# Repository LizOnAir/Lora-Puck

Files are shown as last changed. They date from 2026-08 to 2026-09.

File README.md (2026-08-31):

# Lora-Puck
A Lora module with a AHT20 sensors and LCD display to show status. I made this to discover about how to use LoRa for communication.

Screenshot 2026-08-31 at 10 58 07 PM

## Features:
- detect humidity
- detect temperature
- send data via Lora
- low power consumption
- display

## PCB
PCBMODEL

### Schematic
Screenshot 2026-08-13 at 10 35 21 PM

### Layout
Screenshot 2026-08-13 at 10 35 02 PM
Screenshot 2026-08-13 at 10 35 05 PM

Access files in [PCB folder](https://github.com/LizOnAir/Lora-Puck/tree/main/PCB).

For this design, I'm using PCBA from JLCPCB.

## CAD
Screenshot 2026-08-31 at 10 58 07 PM
Screenshot 2026-08-31 at 10 58 02 PM
Screenshot 2026-08-31 at 10 58 21 PM

Made in Fusion360.Liz
Access files in [CAD folder](https://github.com/LizOnAir/Lora-Puck/tree/main/CAD).

### Assembly
1.  Insert 4 heatset onto the 4 mounting holes in the bottom case.
2.  Insert the PCB into the bottom case.
3.  Using hot glue, stick the buttons onto the tactile switches.
4.  Align the holes of PCB onto the holes of the bottom case.
5.  Cover the top case over the bottom case.
6.  Screw them tight together.
7.  Charge the battery and hang it on somewhere to start detect temperature!!

## Firmware
I use Arduino IDE for programming.
- display
- sensors
- sending data via lora

Access files in [Firmware folder](https://github.com/LizOnAir/Lora-Puck/tree/main/Firmware).

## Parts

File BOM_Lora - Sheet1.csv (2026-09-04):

Item Description | Quantity | Price | Source
PCBA: | 1 |  | https://cart.jlcpcb.com/quote?spm=Jlcpcb.Homepage.1006&spm=Jlcpcb.Homepage.1006
Setup Fee |  | $25.56
Stencil |  | $8.21
Panel |  | $0.00
Large Size |  | $0.00
Components (15 items) |  | $61.35
Feeders Loading Fee |  | $21.42
SMT Assembly |  | $1.40
Hand-soldering Labor Fee |  | $3.58
Manual Assembly |  | $0.08
X-Ray Inspection |  | $16.40
Packaging Fee |  | $0.49
Total Standard PCBA Price |  | $138.49

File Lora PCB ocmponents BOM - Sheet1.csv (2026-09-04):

Designator | Comment | Footprint | Manufacturer | Footprint | JLCPCB Part # | Product link | Lib Type | Rec. Order Qty | Unit Price ($) | Total Price ($)
C11,C2,C3 | 10UF | 402 | Samsung Electro-Mechanics | 402 | C15525 | https://jlcpcb.com/partdetail/16204-CL05A106MQ5NUNC/C15525 | Basic | 20 | 0.0256 | 0.512
J1 | USB_C_Receptacle_USB2.0_14P | USB_C_Receptacle_G-Switch_GT-USB-7010ASV | SHOU HAN | USB_C_Receptacle_G-Switch_GT-USB-7010ASV | C2765186 | https://jlcpcb.com/partdetail/SHOUHAN-TYPE_C_16PIN_2MD_073/C2765186 | Extended | 3 | 0.0743 | 0.2229
SW1,SW2 | SW_Push | SW_SPST_TS-1088-xR020 | XUNPU | SW_SPST_TS-1088-xR020 | C720477 | https://jlcpcb.com/partdetail/XUNPU-TS_1088AR02016/C720477 | Basic | 8 | 0.0556 | 0.4448
L1 | 15uH | 603 | microgate | 603 | C486329 | https://jlcpcb.com/partdetail/microgate-MGFL1608F150MTLF/C486329 | Extended | 6 | 0.0384 | 0.2304
R1,R2 | 5.1k | 402 | UNI-ROYAL(Uniroyal Elec) | 402 | C25905 | https://jlcpcb.com/partdetail/26648-0402WGF5101TCE/C25905 | Basic | 20 | 0.0026 | 0.052
Y1 | 32MHz | Crystal_SMD_Abracon_ABM10-4Pin_2.5x2.0mm | NDK | Crystal_SMD_Abracon_ABM10-4Pin_2.5x2.0mm | C843260 | https://jlcpcb.com/partdetail/NDK-NX2016SA_32MHZ_STD_CZS5/C843260 | Extended | 5 | 0.3518 | 1.759
R5,R6 | 10k | 402 | UNI-ROYAL(Uniroyal Elec) | 402 | C25744 | https://jlcpcb.com/partdetail/26487-0402WGF1002TCE/C25744 | Basic | 20 | 0.0031 | 0.062
U2 | SX1262IMLTRT | QFN-24-1EP_4x4mm_P0.5mm_EP2.6x2.6mm | SEMTECH | QFN-24-1EP_4x4mm_P0.5mm_EP2.6x2.6mm | C191341 | https://jlcpcb.com/partdetail/SEMTECH-SX1262IMLTRT/C191341 | Extended | 2 | 3.1938 | 6.3876
C7,C8 | 4.7uF | 402 | Samsung Electro-Mechanics | 402 | C23733 | https://jlcpcb.com/partdetail/24469-CL05A475MP5NRNC/C23733 | Basic | 20 | 0.0233 | 0.466
U8 | TP4056-42-ESOP8 | SOIC-8-1EP_3.9x4.9mm_P1.27mm_EP2.41x3.3mm_ThermalVias | TOPPOWER(Nanjing Extension Microelectronics) | SOIC-8-1EP_3.9x4.9mm_P1.27mm_EP2.41x3.3mm_ThermalVias | C16581 | https://jlcpcb.com/partdetail/17264-TP4056_42ESOP8/C16581 | Extended | 2 | 0.1843 | 0.3686
C1,C4,C5,C6 | 100nF | 402 | Samsung Electro-Mechanics | 402 | C1525 | https://jlcpcb.com/partdetail/1877-CL05B104KO5NNNC/C1525 | Basic | 20 | 0.0051 | 0.102
U3 | AP2112K-3.3 | SOT-23-5 | TECH PUBLIC | SOT-23-5 | C23380830 | https://jlcpcb.com/partdetail/TECHPUBLIC-AP2112K_33TRG1/C23380830 | Extended | 5 | 0.1104 | 0.552
U4 | AHT20_C2757850 | AHT20_C2757850 | Aosong (Guangzhou) Elec | AHT20_C2757850 | C2757850 | https://jlcpcb.com/partdetail/Aosong_Guangzhou_Elec-AHT20/C2757850 | Extended | 2 | 0.7944 | 1.5888
U1 | ESP32-S3-WROOM-1 | ESP32-S3-WROOM-1 | Espressif Systems | ESP32-S3-WROOM-1 | C2913202 | https://jlcpcb.com/partdetail/3198300-ESP32_S3_WROOM_1N16R8/C2913202 | Extended | 2 | 5.1335 | 10.267
AE1 | Antenna | U.FL_Hirose_U.FL-R-SMT-1_Vertical | HJ Tech | U.FL_Hirose_U.FL-R-SMT-1_Vertical | C2831497 | https://jlcpcb.com/partdetail/HJTech-434MHz_SMA_Flexibleantenna/C2831497 | Extended | 2 | 1.8699 | 3.7398
PCB Assembled Qty：2 |  |  |  |  |  |  |  |  |  | Est. Total Price：26.7920 (Pre-order parts require a quotation for final pricing.)

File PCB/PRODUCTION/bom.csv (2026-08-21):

Designator | Footprint | Quantity | Value | LCSC Part #
_5, _4, _3, _2, |  | 5
AE1 | U.FL_Hirose_U.FL-R-SMT-1_Vertical | 1 | Antenna
C1, C4, C5, C6 | 0402 | 4 | 100nF
C11, C2, C3 | 0402 | 3 | 10UF
C7, C8 | 0402 | 2 | 4.7uF
CN2 | JST_PH_S2B-PH-K_1x02_P2.00mm_Horizontal | 1 | PH-2AK | C8886
J1 | USB_C_Receptacle_G-Switch_GT-USB-7010ASV | 1 | USB_C_Receptacle_USB2.0_14P
L1 | 0603 | 1 | 15uH
R1, R2 | 0402 | 2 | 5.1k
R3 | 0402 | 1 | TBD
R5, R6 | 0402 | 2 | 10k
SW1, SW2 | SW_SPST_TS-1088-xR020 | 2 | SW_Push
U1 | ESP32-S3-WROOM-1 | 1 | ESP32-S3-WROOM-1
U2 | QFN-24-1EP_4x4mm_P0.5mm_EP2.6x2.6mm | 1 | SX1262IMLTRT
U3 | SOT-23-5 | 1 | AP2112K-3.3
U4 | AHT20_C2757850 | 1 | AHT20_C2757850 | C2757850
U6 | PinHeader_1x04_P2.54mm_Vertical | 1 | ~
U8 | SOIC-8-1EP_3.9x4.9mm_P1.27mm_EP2.41x3.3mm_ThermalVias | 1 | TP4056-42-ESOP8
Y1 | Crystal_SMD_Abracon_ABM10-4Pin_2.5x2.0mm | 1 | 32MHz

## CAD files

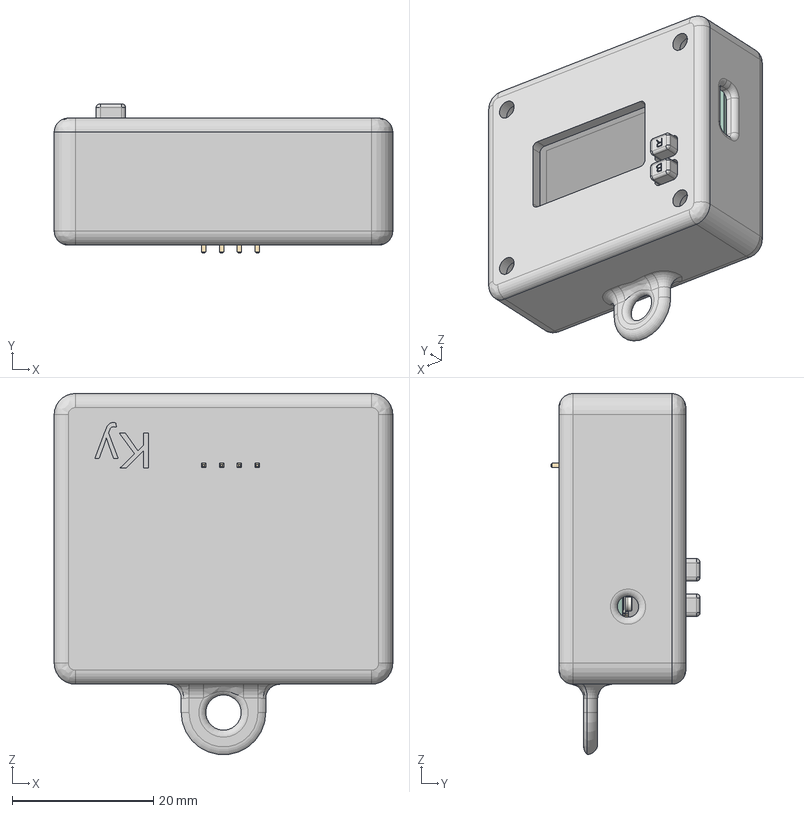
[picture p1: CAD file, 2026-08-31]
CAD/LoraFullModel.step
48.0 x 21.1 x 51.2 mm
PinHeader_1x04_P2.54mm_Vertical
JST_PH_S2B-PH-K_1x02_P2.00mm_Horizontal

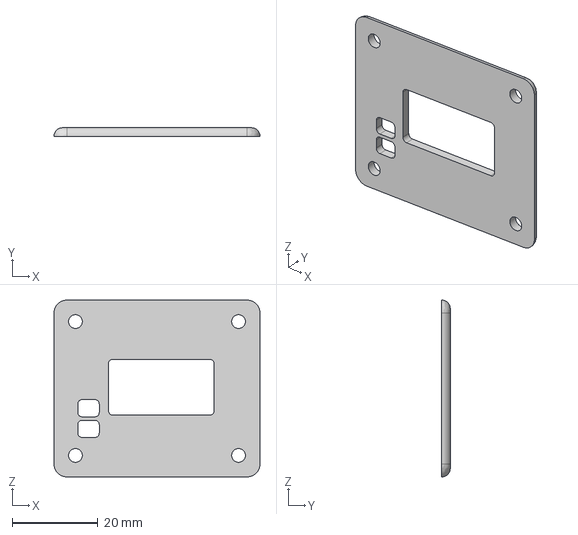
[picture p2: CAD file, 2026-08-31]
CAD/Top.step
48.0 x 2.00 x 41.2 mm

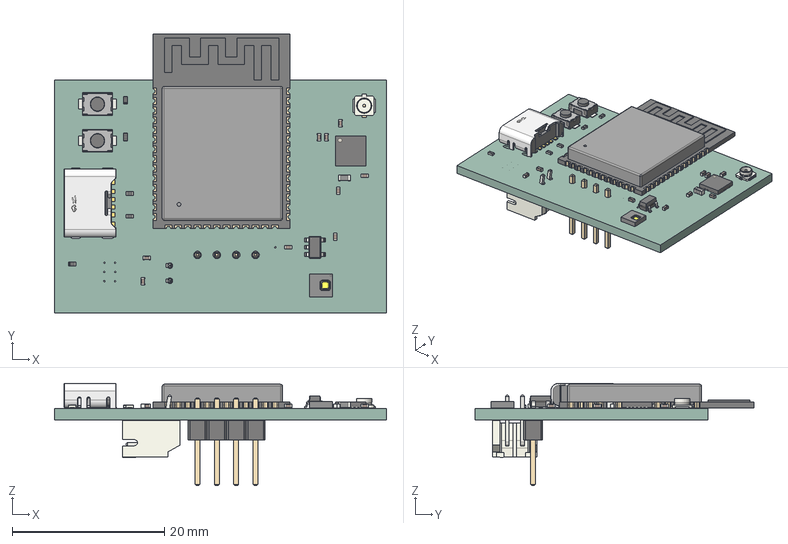
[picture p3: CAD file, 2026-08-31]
CAD/Lora.step
43.6 x 36.6 x 13.4 mm
SOT-23-5
C_0402_1005Metric x 9
U.FL_Hirose_U.FL-R-SMT-1_Vertical
AHT20_C2757850
R_0402_1005Metric x 5
ESP32-S3-WROOM-1
L_0603_1608Metric
QFN-24-1EP_4x4mm_P0.5mm_EP2.6x2.6mm
SW_SPST_TS-1088-xR020 x 2
USB-TYPE-C-009
PinHeader_1x04_P2.54mm_Vertical
JST_PH_S2B-PH-K_1x02_P2.00mm_Horizontal
Lora_PCB

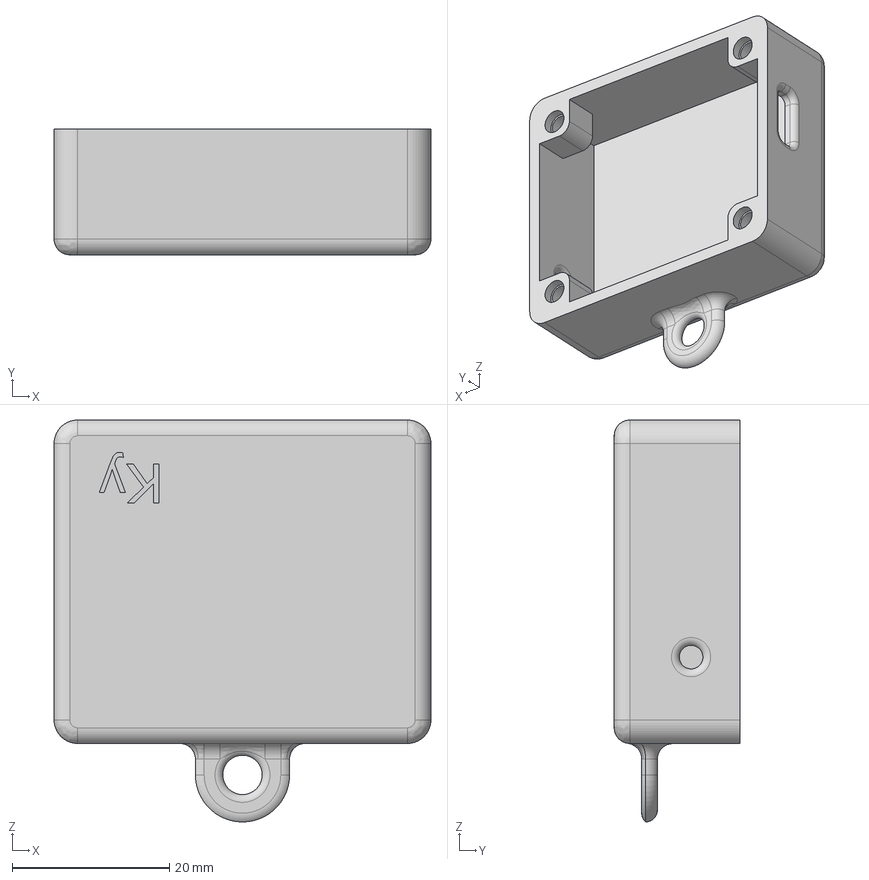
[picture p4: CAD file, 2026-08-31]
CAD/Base.step
48.0 x 16.0 x 51.2 mm

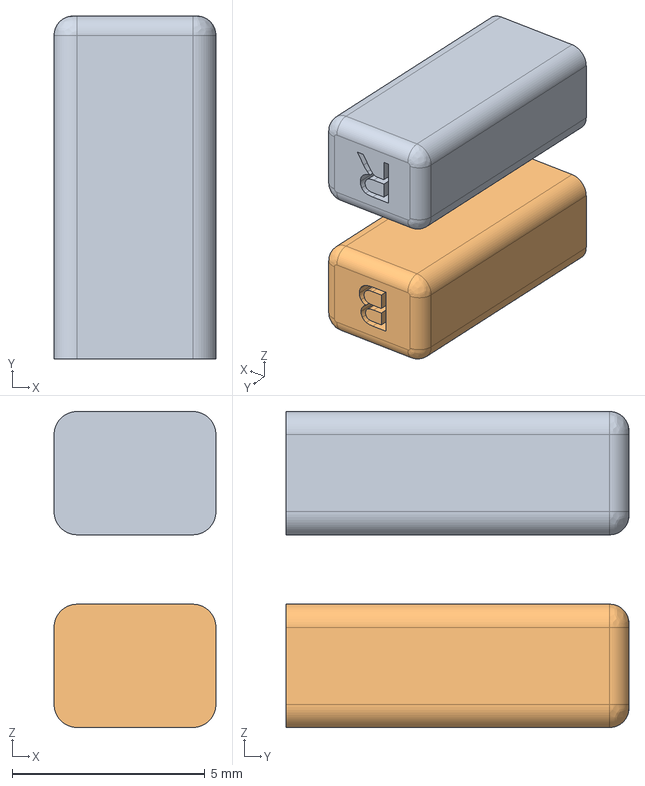
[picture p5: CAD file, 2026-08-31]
CAD/Buttons.step
4.20 x 8.90 x 8.20 mm

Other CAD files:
CAD/Lora.f3z

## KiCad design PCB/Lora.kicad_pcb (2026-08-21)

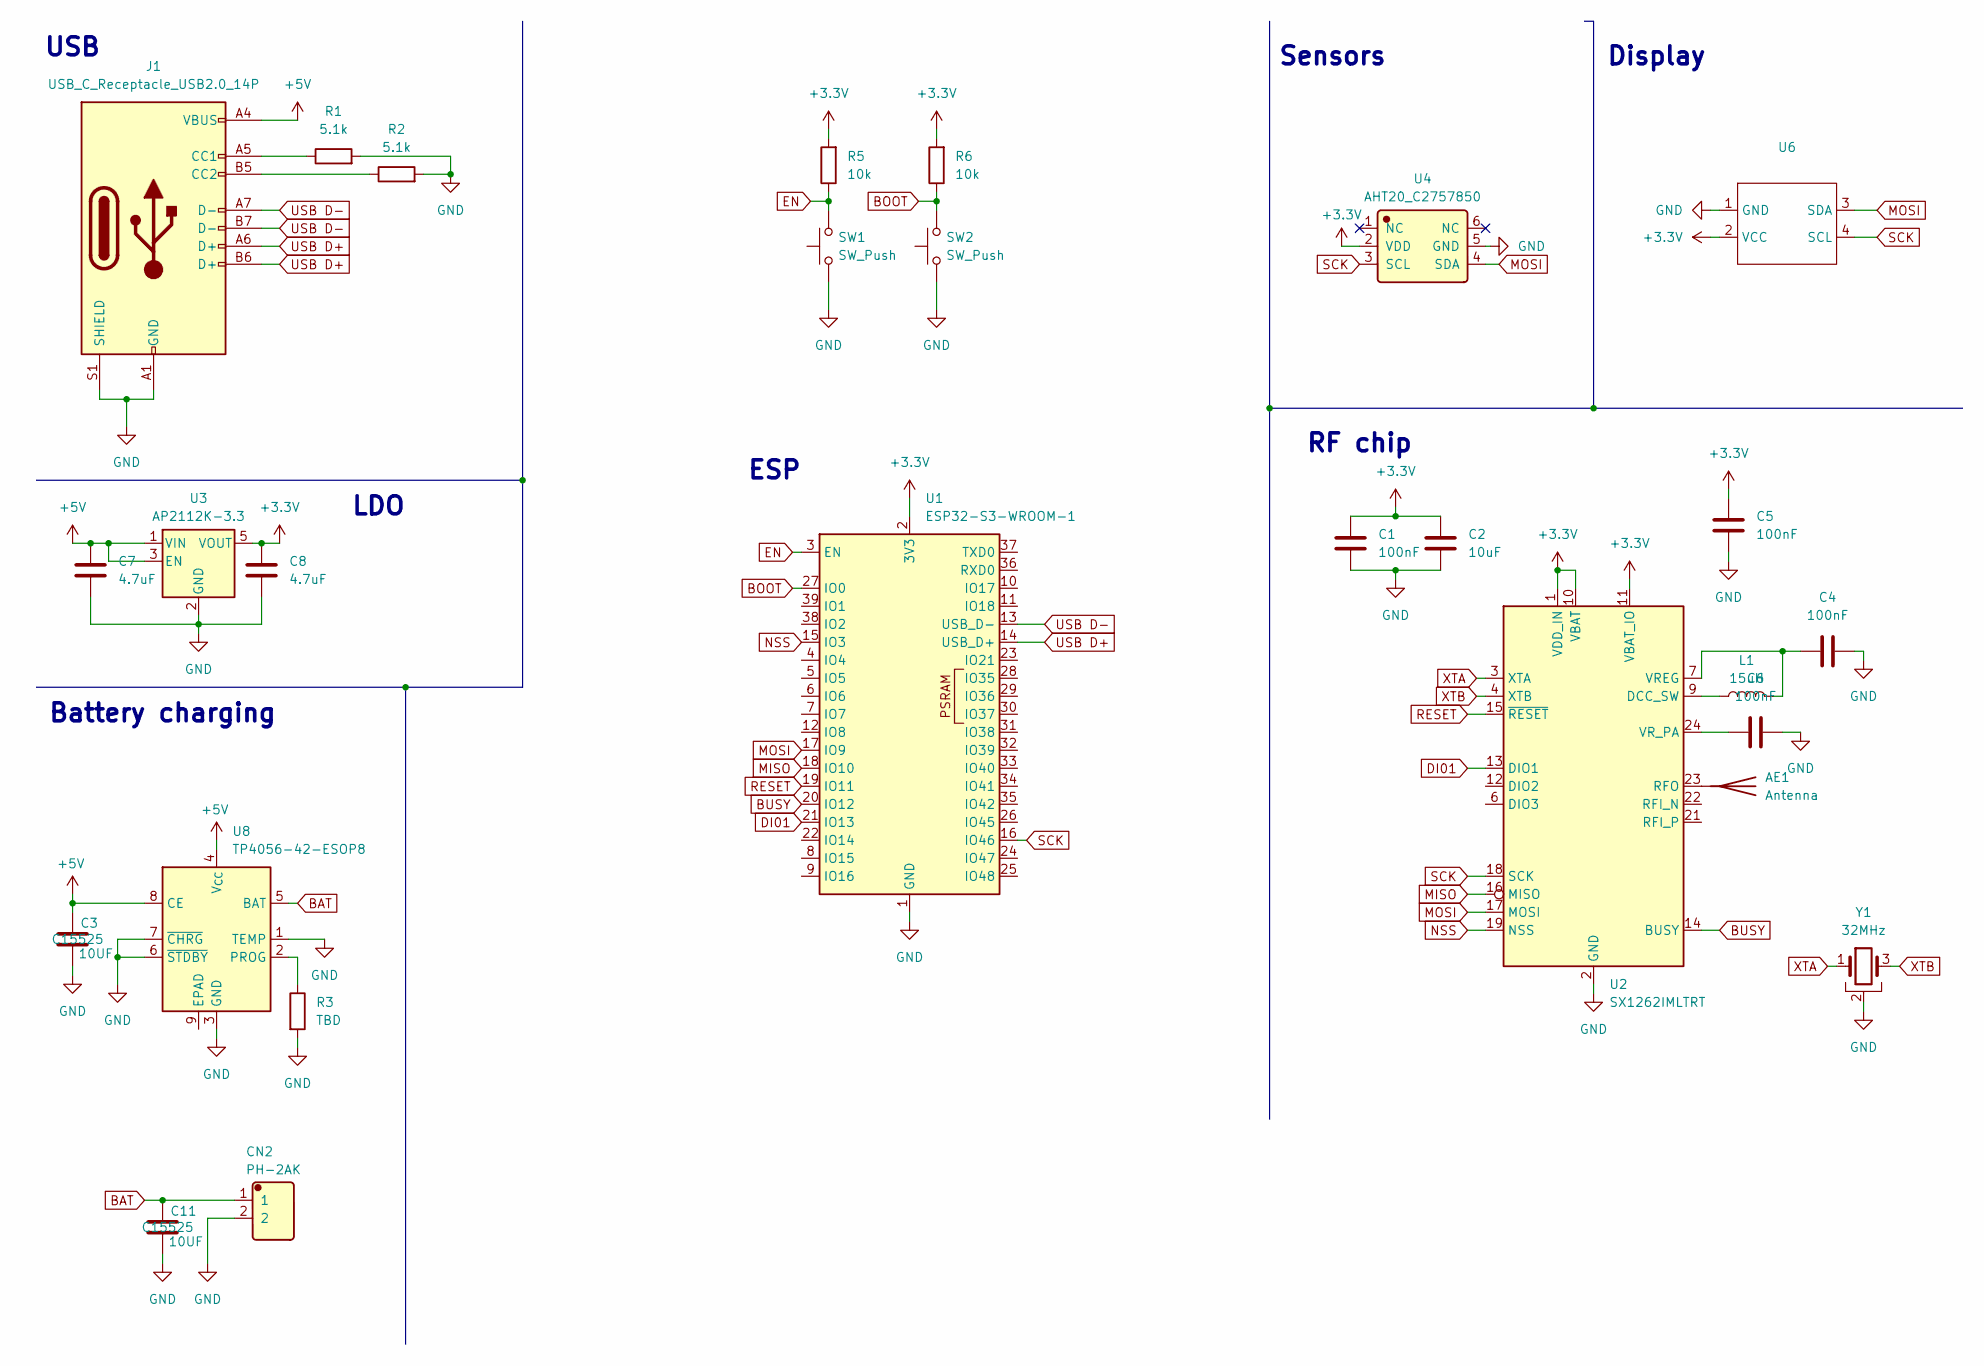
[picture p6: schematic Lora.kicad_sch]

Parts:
AE1: Antenna; U.FL_Hirose_U.FL-R-SMT-1_Vertical
C1, C4, C5, C6: 100nF; C_0402_1005Metric
C2: 10uF; C_0402_1005Metric
C3, C11: 10UF; C_0402_1005Metric; MNF part num C15525
C7, C8: 4.7uF; C_0402_1005Metric
CN2: PH-2AK; JST_PH_S2B-PH-K_1x02_P2.00mm_Horizontal; Manufacturer Part PH-2AK; LCSC C8886
J1: USB_C_Receptacle_USB2.0_14P; USB_C_Receptacle_G-Switch_GT-USB-7010ASV
L1: 15uH; L_0603_1608Metric
R1, R2: 5.1k; R_0402_1005Metric
R3: TBD; R_0402_1005Metric
R5, R6: 10k; R_0402_1005Metric
SW1, SW2: SW_Push; SW_SPST_TS-1088-xR020
U1: ESP32-S3-WROOM-1
U2: SX1262IMLTRT; QFN-24-1EP_4x4mm_P0.5mm_EP2.6x2.6mm
U3: AP2112K-3.3; SOT-23-5
U4: AHT20_C2757850; Manufacturer Part AHT20; LCSC C2757850
U6: PinHeader_1x04_P2.54mm_Vertical
U8: TP4056-42-ESOP8; SOIC-8-1EP_3.9x4.9mm_P1.27mm_EP2.41x3.3mm_ThermalVias
Y1: 32MHz; Crystal_SMD_Abracon_ABM10-4Pin_2.5x2.0mm

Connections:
+3.3V: C1.1, C2.1, C5.2, C8.2, R5.2, R6.2, U1.2 (3V3), U2.1 (VDD_IN), U2.10 (VBAT), U2.11 (VBAT_IO), U3.5 (VOUT), U4.2 (VDD), U6.2 (VCC)
+5V: C3.1, C7.2, J1.A4 (VBUS), J1.A9 (VBUS), J1.B4 (VBUS), J1.B9 (VBUS), U3.1 (VIN), U3.3 (EN), U8.4 (V_{CC}), U8.8 (CE)
BAT: C11.1, CN2.1, U8.5 (BAT)
BOOT: R6.1, SW2.2, U1.27 (IO0)
BUSY: U1.20 (IO12), U2.14 (BUSY)
DI01: U1.21 (IO13), U2.13 (DIO1)
EN: R5.1, SW1.2, U1.3 (EN)
GND: C1.2, C2.2, C3.2, C4.1, C5.1, C6.1, C7.1, C8.1, C11.2, CN2.2, J1.A1 (GND), J1.A12 (GND), J1.B1 (GND), J1.B12 (GND), J1.S1 (SHIELD), R1.2, R2.2, R3.2, SW1.1, SW2.1, U1.1 (GND), U1.40 (GND), U1.41 (GND), U2.2 (GND), U2.5 (GND), U2.8 (GND), U2.20 (GND), U2.25 (GND), U3.2 (GND), U4.5 (GND), U6.1 (GND), U8.1 (TEMP), U8.3 (GND), U8.6 (~STDBY), U8.7 (~CHRG), Y1.2
MISO: U1.18 (IO10), U2.16 (MISO)
MOSI: U1.17 (IO9), U2.17 (MOSI), U4.4 (SDA), U6.3 (SDA)
NSS: U1.15 (IO3), U2.19 (NSS)
unnamed: AE1.1 (A), U2.23 (RFO)
unnamed: J1.A5 (CC1), R1.1
unnamed: J1.B5 (CC2), R2.1
unnamed: L1.1, U2.9 (DCC_SW)
unnamed: C4.2, L1.2, U2.7 (VREG)
unnamed: C6.2, U2.24 (VR_PA)
unnamed: R3.1, U8.2 (PROG)
RESET: U1.19 (IO11), U2.15 (~RESET)
SCK: U1.16 (IO46), U2.18 (SCK), U4.3 (SCL), U6.4 (SCL)
USB D+: J1.A6 (D+), J1.B6 (D+), U1.14 (USB_D+)
USB D-: J1.A7 (D-), J1.B7 (D-), U1.13 (USB_D-)
XTA: U2.3 (XTA), Y1.1
XTB: U2.4 (XTB), Y1.3

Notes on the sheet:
USB
ESP
Display
LDO
Sensors
RF chip
Battery charging

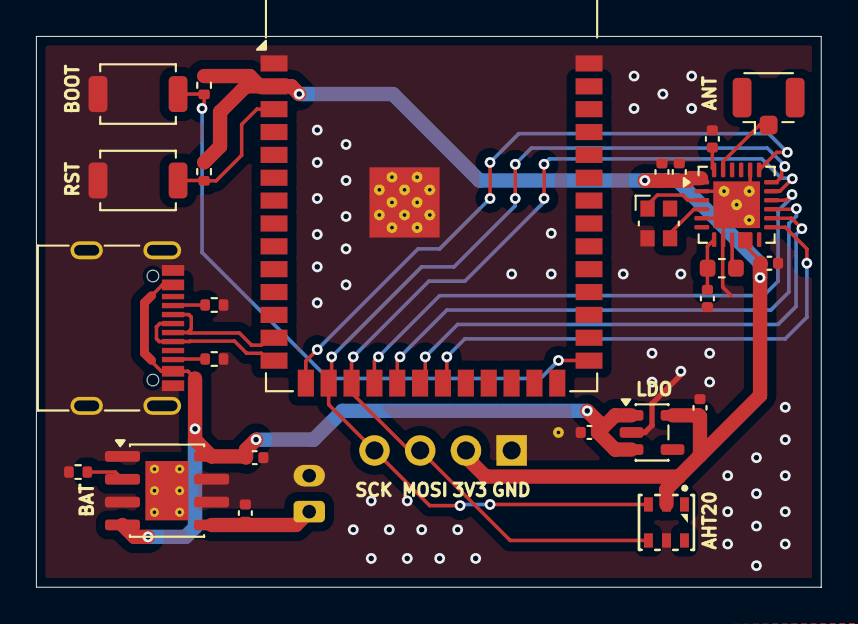
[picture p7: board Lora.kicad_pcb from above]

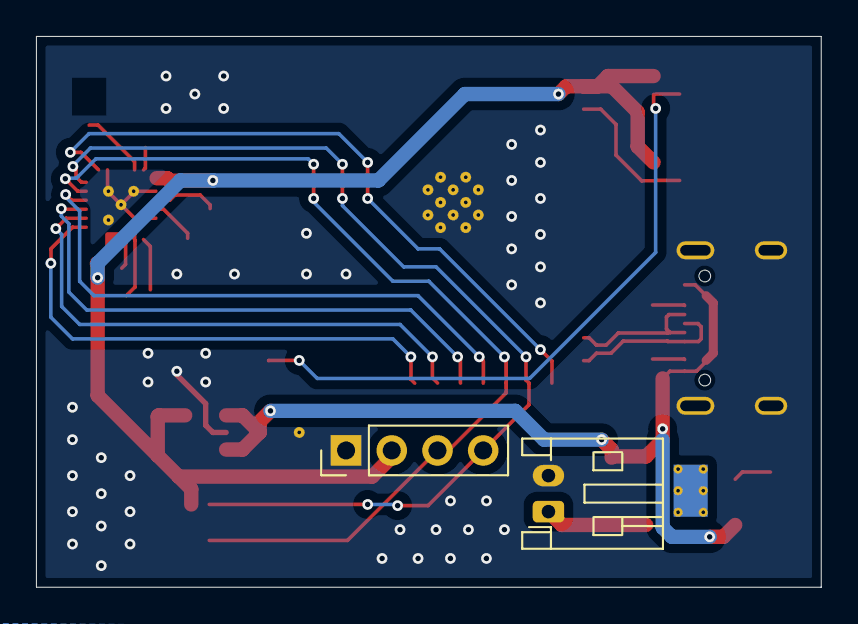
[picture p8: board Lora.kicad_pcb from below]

Board: 2 copper layers, 43.6 x 30.6 mm, 27 parts (2 on the bottom side), 24 nets.

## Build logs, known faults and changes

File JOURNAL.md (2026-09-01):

---
title: Lora Puck
author: Liz
description: A Lora module with a AHT20 sensors and LCD display to show status
created_at: 2026-07-16
---
### Total time spent: 13.9 Hours

## Day 1 - Getting started! - July 16th - 2.5 Hours
I wanted to make a Lora Puck to learn more about frequency and radio wave.
I read through the [Lora guide](https://stasis.hackclub.com/starter-projects/meshtastic-lora) to learn about the basics, the schematic connection and pcb layout. 

Starting with the schematic, I connect the decoupling capacitors, resistors, antenna chip according to the guide. 
I added battery management system as well because I want it to be portable and I need to charge the battery. I went online to look for a suitable battery management system and the datasheet. Referring to the example application circuit, I drew a function block for that.  Then, I went to double check those connection. 
Screenshot 2026-08-21 at 3 04 36 PM

### PCB Layout Time!!
I carefully take note of which capacitor need to be close with which pins to lower the noise. I group the components together with their function block. Then I only start placing them as compact as possible as I want the board to be small. 

Then I started routing. I tried to routed the antenna as short as possible. Then the differential pair (USB +-) and power lines. And finally the other lines. 

## Day 2 - Routing + Fix DRC errors - July 17th - 1.2 Hours

I finished routing the board. 
Initially, I planned to pour ground plane on the bottom copper layer and 3v3 plane on the top copper layer. But considering it might affect the impedance of the board and change the antenna magnetic field, I choose a safer path, which is to pour ground on both copper layer. 

Then i when through all the errors, mostly are just some connection i missed out to connect, but I was stuck at one of the error which told me to connect from copper plane to copper plane. I couldn't find what's wrong with it. 
With advice from slack, I put some sticthing vias to fix the problem.

Screenshot 2026-08-21 at 3 02 46 PM

## Day 3 - Modifying Design - July 22th - 2 Hours

I took a break from this project to work on my other project. 
After coming back, I decided to add a humidity sensor and a e-ink display to my Lora module so it can send data via the Lora and display.

Screenshot 2026-08-21 at 3 26 47 PM

Transforming a simple Lora module into a weather monitor device. Increasing it's functionality.

I went to check the pins to make sure they are compatible.

Screenshot 2026-08-13 at 10 35 21 PM

Since I can’t find footprint for the display and sensors, I drew it myself.

## Day 4 - Rerouting - July 23th - 1.5 Hours

Since I added some new components, I have to modify the placement of the components and reroute it.

Screenshot 2026-08-21 at 4 37 43 PM

## Day 5 - Change Display - August 12th - 0.5 hours

After reviewing the new version of the pcb, the e-ink display that I picked earlier made the device too big and awkward to carry around. So I changed the e-ink display to a smaller 0.96 inch LCD display. Now it looks much more compact and better to carry around.

Screenshot 2026-08-21 at 4 52 24 PM

## Day 6 - Rerouting & Double check  - August 12th - 1.2 hours

I rerouted some lines. I was trying to make the lines from the antenna chip to the esp chip more neater with enough spacing to prevent interference of magnetic field. It took me some experiments before finding the best way to route it. Finally I went on to double check everything and added text on the PCB.

Screenshot 2026-08-21 at 5 15 49 PM

## Day 7 - Programming - August 31st - 4.7 hours

I went to research like how to code Lora cause I have no idea. So I found that there’s like LoRaWan, Lora Alliance. Initially I wanted the Lora module to communicate directly to my phone or via website. I wanted to use LoraWan with the gateway to connect to phone using The Things(open source free gateway) After digging more into it, I found that it need to connect to the gateway using cables. Since there aren’t any nearby my area, I was forced to switch plan. Instead of loraWan, I switch to using two LoRa module to communicate to each other. I found some library (RadioLib, Adafruit AHTX0, Adafruit SH1106) for programming the Lora chip, sensors and display. 

Screenshot 2026-09-01 at 1 09 46 AM

I decided to make a CAD case for the Lora module, so it can stay outdoor during rain and function normally. I start by importing the pcb and the display then draft a square shape for the base. I also went back to Kicad to measure the dimension of the board to make sure it’s correct. After that, I simply extrude the square so it covers the whole pcb and display. I leave the display part open and it’s almost done. But it feels too simple and plain. So I was thinking of adding some wedges or something where a string can attach to it, making it easier to tie on a tree or hanging it somewhere. I changed a few version, on the side / top, and found that a simple hole on the top fit the best. I also make buttons with the B and R carve on it. 

Screenshot 2026-08-31 at 10 58 07 PM

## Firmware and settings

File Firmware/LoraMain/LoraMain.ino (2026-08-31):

//main
#include <Adafruit_GFX.h>
#include <Adafruit_SSD1306.h>
#include <RadioLib.h>
#include <Adafruit AHTx0>

#define INITIATING_NODE

//LoRa pin
#define loraSCKpin 46;
#define loraMISOpin 10;
#define loraMOSIpin 9;
#define loraNSSpin 3;
#define loraRSTpin 11;
#define loraBUSYpin 12;
#define loraDIO1pin 13;

//sensor pin
#define sensorMOSI 9;
#define sensorSCK 46;

//display pin
#define displayMOSI 9;
#define displaySCK 46;

#define SCREEN_WIDTH 128
#define SCREEN_HEIGHT 64
#define OLED_RESET -1

Adafruit_SSD1306 display(SCREEN_WIDTH, SCREEN_HEIGHT, &Wire, OLED_RESET);

//NSS, DI01, NRST, BUSY
SX1262 radio = new Module(loraNSSpin, loraDIO1pin, loraRSTpin, loraBUSYpin);

// save transmission states between loops
int transmissionState = RADIOLIB_ERR_NONE;

// flag to indicate transmission or reception state
bool transmitFlag = false;

// flag to indicate that a packet was sent or received
volatile bool operationDone = false;

#if defined(ESP32)
  ICACHE_RAM_ATTR
#endif

void setFlag(void) {
  // we sent or received a packet, set the flag
  operationDone = true;
}

void setup() {
  Serial.begin(9600);

  // initialize SX1262 at 434 MHz
  Serial.print(F("[SX1262] Initializing ... "));
  ConfigLoRa_t config;
  config.frequency = 434;
  int state = radio.begin(config);
  if (state == RADIOLIB_ERR_NONE) {
    Serial.println(F("success!"));
  } else {
    Serial.print(F("failed, code "));
    Serial.println(state);
    while (true) { delay(10); }
  }

  // set the function that will be called
  // when new packet is received
  radio.setDio1Action(setFlag);

  #if defined(INITIATING_NODE)
    // send the first packet on this node
    Serial.print(F("[SX1262] Sending first packet ... "));
    transmissionState = radio.startTransmit(temp.temperature, humidity.relative_humidity);
    transmitFlag = true;
  #else
    // start listening for LoRa packets on this node
    Serial.print(F("[SX1262] Starting to listen ... "));
    state = radio.startReceive();
    if (state == RADIOLIB_ERR_NONE) {
      Serial.println(F("success!"));
    } else {
      Serial.print(F("failed, code "));
      Serial.println(state);
      while (true) { delay(10); }
    }
  #endif

  if (!aht.begin()) {
    Serial.println("Could not find AHT");
    while (1)
      delay(10);
  }
  Serial.println("AHT10 or AHT20 found");

  display.begin(SSD1306_SWITCHCAPVCC, 0x3C);
  display.clearDisplay();
  display.setTextSize(1);
  display.setTextColor(SSD1306_WHITE);
  display.setCursor(0, 30);
  display.println("Display Init...");
  display.display();
  delay(1000);

}

void loop() {
  sensors_event_t humidity, temp;
  aht.getEvent(&humidity,
               &temp); // populate temp and humidity objects with fresh data
  Serial.print("Temperature: ");
  Serial.print(temp.temperature);
  Serial.println(" degrees C");
  Serial.print("Humidity: ");
  Serial.print(humidity.relative_humidity);
  Serial.println("% rH");

  delay(500);

  // check if the previous operation finished
  if(operationDone) {
    // reset flag
    operationDone = false;

    if(transmitFlag) {
      // the previous operation was transmission, listen for response
      // print the result
      if (transmissionState == RADIOLIB_ERR_NONE) {
        // packet was successfully sent
        Serial.println(F("transmission finished!"));

      } else {
        Serial.print(F("failed, code "));
        Serial.println(transmissionState);

      }

      // listen for response
      radio.startReceive();
      transmitFlag = false;

    } else {
      // the previous operation was reception
      // print data and send another packet
      String str;
      int state = radio.readData(str);

      if (state == RADIOLIB_ERR_NONE) {
        // packet was successfully received
        Serial.println(F("[SX1262] Received packet!"));

        // print data of the packet
        Serial.print(F("[SX1262] Data:\t\t"));
        Serial.println(str);

        // print RSSI (Received Signal Strength Indicator)
        Serial.print(F("[SX1262] RSSI:\t\t"));
        Serial.print(radio.getRSSI());
        Serial.println(F(" dBm"));

        // print SNR (Signal-to-Noise Ratio)
        Serial.print(F("[SX1262] SNR:\t\t"));
        Serial.print(radio.getSNR());
        Serial.println(F(" dB"));
      }

      // wait a second before transmitting again
      delay(10000);

      // send another one
      Serial.print(F("[SX1262] Sending another packet ... "));
      transmissionState = radio.startTransmit(temp.temperature, humidity.relative_humidity);
      transmitFlag = true;
    }
  
  }
  display.setCursor(0, 20);
  display.print("Data:");
  display.setCursor(0, 30);
  display.print(temp.temperature,humidity.relative_humidity);
  display.display();
  render();  

}

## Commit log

2026-08-21 Add project journal for Lora Puck development
    Documented the development process of the Lora Puck project, including initial setup, PCB layout, routing, and design modifications.
2026-09-01 Enhance CAD case design description in JOURNAL.md
    Added details about the design process for the CAD case, including the addition of buttons and improvements for outdoor use.
2026-09-04 Rename BOM_Lora - Sheet1 (1).csv to BOM_Lora - Sheet1.csv
    [BOM_Lora - Sheet1.csv]
